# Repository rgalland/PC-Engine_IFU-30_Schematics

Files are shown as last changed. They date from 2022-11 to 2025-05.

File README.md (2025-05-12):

# PC-Engine IFU-30 Reverse engineering
This repository contains:
* kicad files of the main PCB schematics
* kicad files of the RAM mezzanine PCB
* wiki page to explain the circuitry

Potential future development:
* creation of a compatible PCB using SMD component to shrink the board a bit and include RAM on it as well
* add a header for an easy RGB modification

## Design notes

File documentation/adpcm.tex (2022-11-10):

%% LyX 2.3.6 created this file.  For more info, see http://www.lyx.org/.
%% Do not edit unless you really know what you are doing.
\documentclass[english]{article}
\usepackage[T1]{fontenc}
\usepackage[latin9]{inputenc}
\usepackage{babel}
\usepackage{amssymb}
\usepackage{graphicx}
\usepackage[unicode=true]
 {hyperref}
\begin{document}
\title{ADPCM Amplification}
\maketitle

\section{Introduction}

Before being mixed to the audio left and right signals, the ADPCM
signal generated by the M5205 is biased and shrunk, re-amplified and
goes through a few low pass filters.
\begin{figure}
\caption{ADPCM Filter Circuit}

\begin{centering}
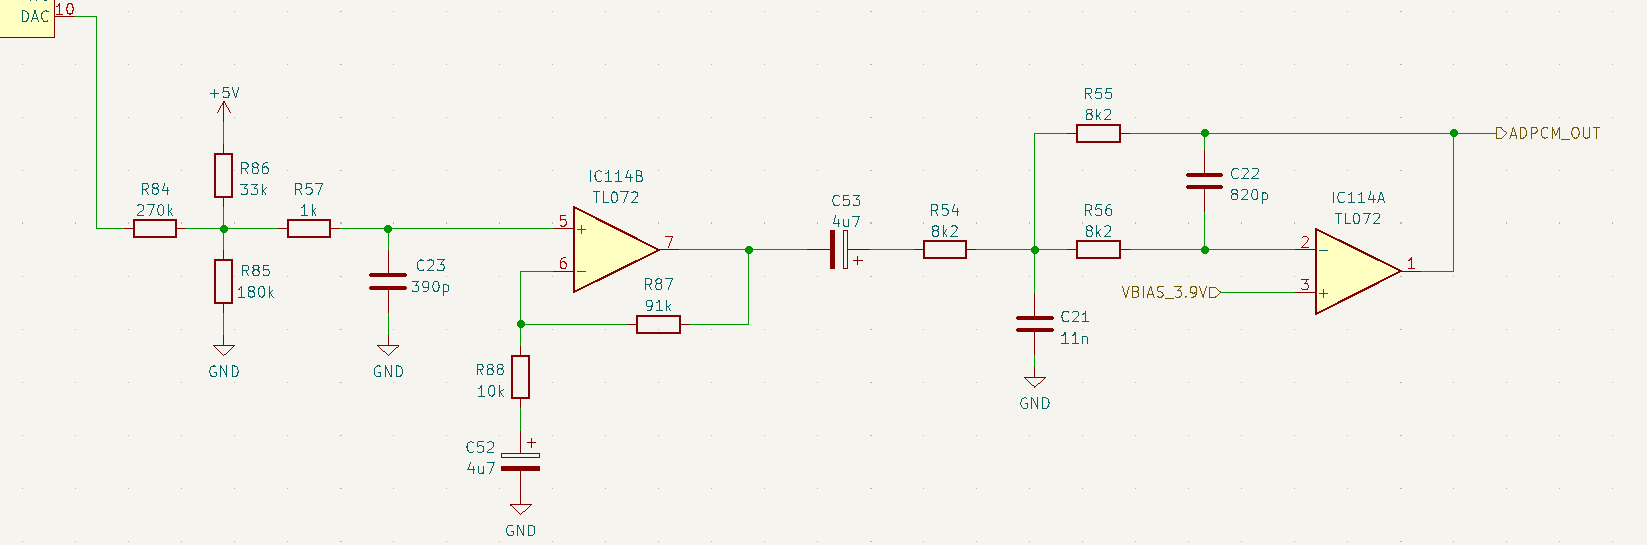
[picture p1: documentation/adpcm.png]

\par\end{centering}
\end{figure}

\section{Biasing}

\begin{figure}
\caption{Biasing and Passive Low-pass Filter}

\begin{centering}
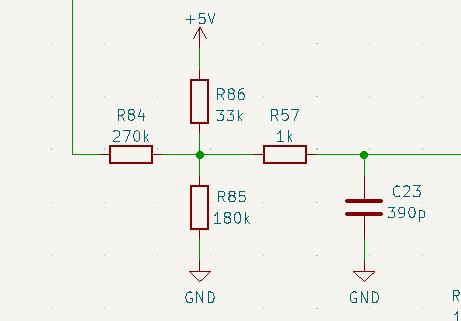
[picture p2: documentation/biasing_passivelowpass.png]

\par\end{centering}
\end{figure}
The biasing is introducted by the R86 and R85 bridge divider connected
to 5V (see Figure 2). We will start with the calculation of the Thevenin
equivalent circuit at R85.

\[
V_{TH_{R85}}=\frac{V_{DAC}/R84+5V/R86+0/R85}{1/R84+1/R86+1/R85}=\frac{V_{DAC}/270k+5/33k}{1/270k+1/33k+1/180k}
\]

\[
V_{TH_{R85}}=\frac{V_{DAC}}{10.682}+3.83V
\]

\[
R_{TH_{R85}}=R84//R86//R85=\frac{1}{1/R84+1/R86+1/R85}=\frac{1}{1/270k+1/33k+1/180k}=25.277k\Omega
\]
As you can see, the DAC output is divided by 10.682 so the signal
is greatly shrunk by the biasing circuit and it is shifted up by 3.83V.

\section{Passive Low-pass filter}

Now that we have determined the Thevenin equivalent, we can calculate
the low pass filter including R57 and C23.

\[
V_{C23}=\frac{Z_{C23}}{R_{TH_{R85}}+R57+Z_{C23}}\times V_{TH_{R85}}=\frac{1/jC23\omega}{R_{TH_{R85}}+R57+1/jC23\omega}\times V_{TH_{R85}}
\]

\[
V_{C23}=\frac{1}{1+j\left(R_{TH_{R85}}+R57\right)C23\omega}\times V_{TH_{R85}}
\]
\linebreak{}
At DC level, when $j\omega=0$, C23 acts an open circuit and therefore
$V_{TH_{R85}}$ is applied directly to V+. $V_{TH_{R85}}$ will include
3.83V and DC bias added in software to VDAC which is typically 2.5V.
Since VDAC is divided by 10.682, a 2.5V DC offset will give 0.234V.
$V_{TH_{R85}}=3.83+0.234\thickapprox4V$\linebreak{}
\linebreak{}
Let's now work out the cut-off frequency of the low-pass filter.

\[
\omega_{C}=\frac{1}{(R_{TH_{R85}}+R57)C23}\rightarrow f_{C}=\frac{1}{2\pi(R_{TH_{R85}}+R57)C23}=\frac{1}{2\pi\times(25.277k+1k)\times390\times10^{-12}}=15538Hz
\]
\linebreak{}
First order filter with -3dB attenuation at $f_{c}=15538Hz$ and -20dB
per decade.

\section{IC114B - Positive Gain Amplifier}

\begin{figure}
\begin{centering}
\caption{Positive Gain Amplifier}
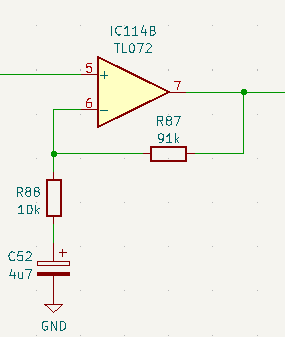
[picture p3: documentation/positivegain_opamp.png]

\par\end{centering}
\end{figure}
IC114B has a negative feedback and the input voltage is connected
to the positive input. Therefore it is configured as an amplifier
with a positive gain. C52 is a fairly large capacitor connected to
ground which ensure gain is only applied at AC level where the opamp
becomes a simple follower at DC level. In other words, the ADPCM signal
is amplified and bias voltage is preserved.\linebreak{}
\linebreak{}
At DC level, when $j\omega=0$, C52 is seen as an open circuit therefore:
\[
V_{IC114B+}=V_{R85}=V_{IC114B-}=V_{IC114BOUT}=4V
\]
AC level, IC114B acts as positive gain amplifer.

\[
V_{IC114B-}=\frac{R88+1/jC52\omega}{R88+1/jC52\omega+R87}\times V_{IC114BOUT}
\]
\linebreak{}
When $j\omega\rightarrow\infty$, capacitors be come short circuits
and we can determine the gain for high frequencies.

\[
V_{IC114B-}=\frac{R88}{R88+R87}\times V_{IC114BOUT}=V_{IC114B+}=V_{R85AC}
\]

\[
Gain=\frac{V_{IC114BOUT}}{V_{R85AC}}=\frac{R88+R87}{R88}=\frac{10k+91k}{10k}=10.1
\]

\[
\frac{V_{IC114BOUT}}{V_{R85AC}}=\frac{R88+1/jC52\omega+R87}{R88+1/jC52\omega}=\frac{1+j(R87+R88)\times C52\omega}{1+jR88C52\omega}
\]
\linebreak{}
To determine the cut frequency of the high-pass filter we know that
gain must be 3dB away from the final final. i.e. $10.1/\sqrt{2}=7.142$

\[
\left|\frac{V_{IC114BOUT}}{V_{R85AC}}\right|=\frac{\left|1+j(R87+R88)\times C52\omega\right|}{\left|1+jR88C52\omega\right|}=\frac{\left|1+j0.4747\omega\right|}{\left|1+j0.047\omega\right|}=\frac{\sqrt{1+0.4747^{2}\omega^{2}}}{\sqrt{1+0.047^{2}\omega^{2}}}
\]

\[
\frac{1+0.4747^{2}\omega_{C}^{2}}{1+0.047^{2}\omega_{C}^{2}}=7.142^{2}=51
\]
\[
1+0.4747^{2}\omega_{C}^{2}=51\times\left(1+0.047^{2}\omega_{C}^{2}\right)
\]

\[
0.4747^{2}\omega_{C}^{2}-51\times0.047^{2}\omega_{C}^{2}=51-1
\]

\[
\omega_{C}^{2}\left(0.4747^{2}-51\times0.047^{2}\right)=50
\]

\[
\omega_{C}=\sqrt{\frac{50}{\left(0.4747^{2}-51\times0.047^{2}\right)}}=21.065
\]
\linebreak{}
It is now possible to work out the cut frequency of the high-pass
filter. 
\[
f_{C}=\frac{\omega_{C}}{2\pi}=\frac{21.065}{2\times3.14}=3.354Hz
\]

\section{IC114A - Multi-Feedback Amplifier}

\begin{figure}

\caption{Multi-Feeback Amplifier}

\begin{centering}
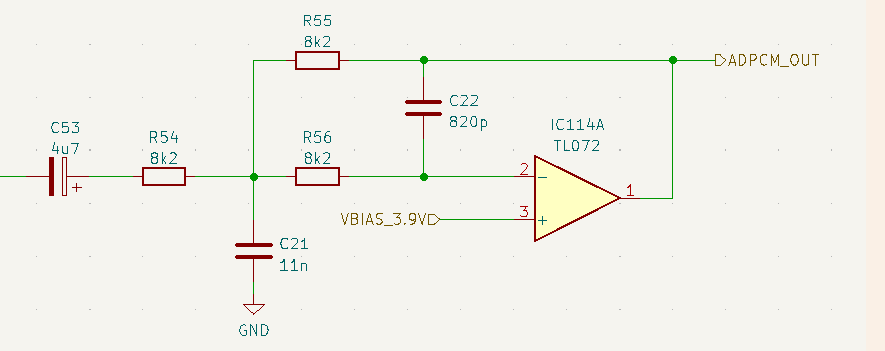
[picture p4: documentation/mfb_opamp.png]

\par\end{centering}
\end{figure}
This opamp is configured as an MFB (multi-feedback) filter which is
a second order low-pass filter but also no gain at DC. For the calculations,
C53 is removed but its purpose is to remove any DC offset before it
is fed to the opamp.\linebreak{}
\linebreak{}
When $j\omega=0$, C53, C21 and C22 act as open circuits. Therefore:

\[
V_{IC114A-}=V_{ADPCMOUT}=V_{IC114B+}=V_{BIAS}=3.90V
\]
When $j\omega\rightarrow\infty$, C22 is a short circuit turning IC114A
into a follower but at this stage C21 is shorting the input signal
to ground so there will be no high-frequency output signal.\linebreak{}
\linebreak{}
To find the transfer function of this opamp circuit, we will break
in down in 2 stages: calculation of voltage at C21 and then calculation
of voltage at IC114A-. To simplify calulations, VBIAS biased will
be switched off to make $V_{IC114A-}=V_{IC114A+}=0V$. With this simplification,
the connection R56 and C22 will be tied to GND. \linebreak{}
\linebreak{}
\[
V_{C21}=\frac{\frac{V_{IC114BOUT}}{R54}+\frac{V_{ADPCMOUT}}{R55}}{\frac{1}{R54}+\frac{1}{R55}+\frac{1}{R56}+jC21\omega}
\]

\[
V_{IC114A-1}=\frac{\frac{V_{ADPCMOUT}}{1/jC22\omega}+\frac{V_{C21}}{R56}}{jC22\omega+\frac{1}{R56}}=0
\]

\[
V_{C21}=-jR56C22\omega\times V_{ADPCMOUT}
\]

\[
\frac{\frac{V_{IC114BOUT}}{R54}+\frac{V_{ADPCMOUT}}{R55}}{\frac{1}{R54}+\frac{1}{R55}+\frac{1}{R56}+jC21\omega}=-jR56C22\omega\times V_{ADPCMOUT}
\]

\[
\frac{V_{IC114BOUT}}{R54}+\frac{V_{ADPCMOUT}}{R55}=-jR56C22\omega\times V_{ADPCMOUT}\times\left(\frac{1}{R54}+\frac{1}{R55}+\frac{1}{R56}+jC21\omega\right)
\]

\[
V_{ADPCMOUT}\times\left(\frac{1}{R55}+jR56C22\omega\times\left(\frac{1}{R54}+\frac{1}{R55}+\frac{1}{R56}+jC21\omega\right)\right)=-\frac{V_{IC114BOUT}}{R54}
\]

\[
\frac{V_{ADPCMOUT}}{V_{IC114BOUT}}=-\frac{1}{R54}\times\frac{1}{\frac{1}{R55}+jR56C22\omega\times\left(\frac{1}{R54}+\frac{1}{R55}+\frac{1}{R56}+jC21\omega\right)}
\]

\[
\frac{V_{ADPCMOUT}}{V_{IC114BOUT}}=-\frac{1}{R54R56}\times\frac{1}{\frac{1}{R55R56}+jC22\omega\times\frac{R55R56+R54R56+R54R55}{R54R55R56}-C21C22\omega^{2}}
\]

\[
\frac{V_{ADPCMOUT}}{V_{IC114BOUT}}=-\frac{1}{R54R56C21C22}\times\frac{1}{\frac{1}{R55R56C21C22}+j\frac{R55R56+R54R56+R54R55}{R54R55R56C21}\omega-\omega^{2}}
\]
\linebreak{}
Since R54=R55=R56, we will replace them with R instead to simplify
the equation:

\[
\frac{V_{ADPCMOUT}}{V_{IC114BOUT}}=-\frac{1}{R^{2}C21C22}\times\frac{1}{\frac{1}{R^{2}C21C22}+j\frac{R^{2}+R^{2}+R^{2}}{R^{3}C21}\omega-\omega^{2}}=-\frac{1}{R^{2}C21C22}\times\frac{1}{\frac{1}{R^{2}C21C22}+j\frac{3}{RC21}\omega-\omega^{2}}
\]

\[
H\left(j\omega\right)=-\frac{1}{1+j3RC22\omega-R^{2}C21C22\omega^{2}}
\]
\linebreak{}
Now that we have the transfer function, we can see that when $j\omega=0$,
the DC gain is 1. \linebreak{}
\linebreak{}
\[
\omega_{C}=\frac{1}{\sqrt{R^{2}C21C22}};\omega_{C}=2\pi f_{C};f_{C}=\frac{1}{2\times\pi\times\sqrt{8.2k\times8.2k\times11\times10^{-9}\times390\times10^{-12}}}=6463Hz
\]
\linebreak{}
The cut-off freuqency is 6463Hz and -40dB percade will be applied
by the filter. The next stage is the Quality factor calculation but
I can't remember how to do that. To get the value, I typed the component
values in \href{http://sim.okawa-denshi.jp/en/OPttool.php}{this link}
and it gave me Q=1.2209.
\end{document}

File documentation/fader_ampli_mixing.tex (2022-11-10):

%% LyX 2.3.6 created this file.  For more info, see http://www.lyx.org/.
%% Do not edit unless you really know what you are doing.
\documentclass[english]{article}
\usepackage[T1]{fontenc}
\usepackage[latin9]{inputenc}
\usepackage{babel}
\usepackage{graphicx}
\usepackage[unicode=true]
 {hyperref}

\makeatletter

%%%%%%%%%%%%%%%%%%%%%%%%%%%%%% LyX specific LaTeX commands.
%% Because html converters don't know tabularnewline
\providecommand{\tabularnewline}{\\}

\makeatother

\begin{document}
\title{Audio Fading, Mixing and Amplification}

\maketitle
\begin{figure}
\caption{Audio Mixing and Amplification}

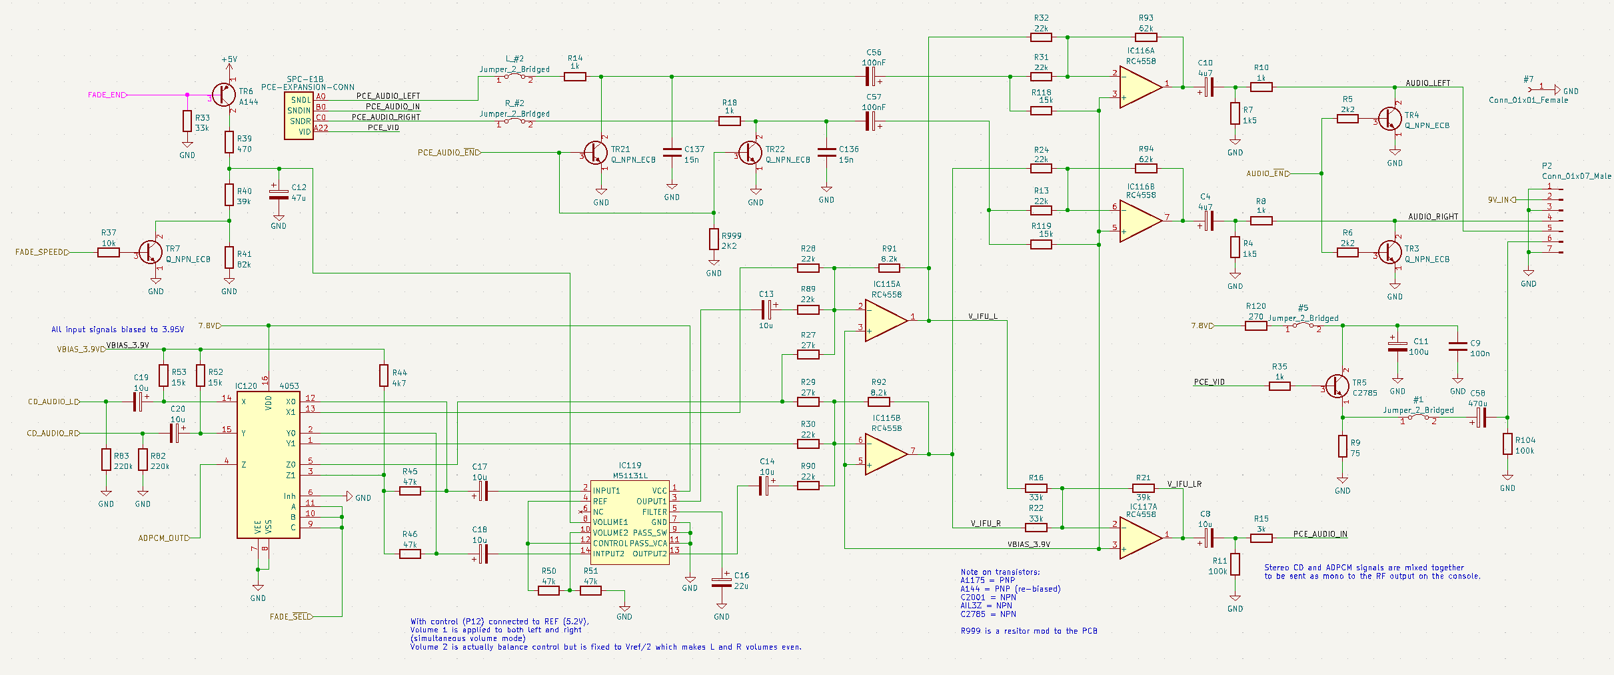
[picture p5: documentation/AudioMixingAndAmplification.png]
\centering{}
\end{figure}

\section{Audio Fading Circuit}

The ADPCM signal and the CD audio left and right channels can be faded
out at 2 different rates via register 180Fh; 2.5s or 6s. In normal
operation i.e. when not fading is applied, TR6 (A144) is constantly
saturated by pulling the base to GND via R33 and this allows C12 to
charge to 5V via R39.\linebreak{}
\linebreak{}
When fading is enabled, the IC output (which I expect to be an open
collector output) to pull up the base to 5V and thus stop sauration.
This will have the effect of discharging C12 through R40 in fast fading
mode and through R40 and R41 in slow fading mode. The fading mode
is controlling TR7: when the IC pulls the base up, it is saturated
which makes it short R41 giving the fast fading mode. When the IC
output is floating, the base no longer receives current and the transistor
is open giving the slow fading mode.

\begin{figure}

\caption{C12 Charging and Discharging}

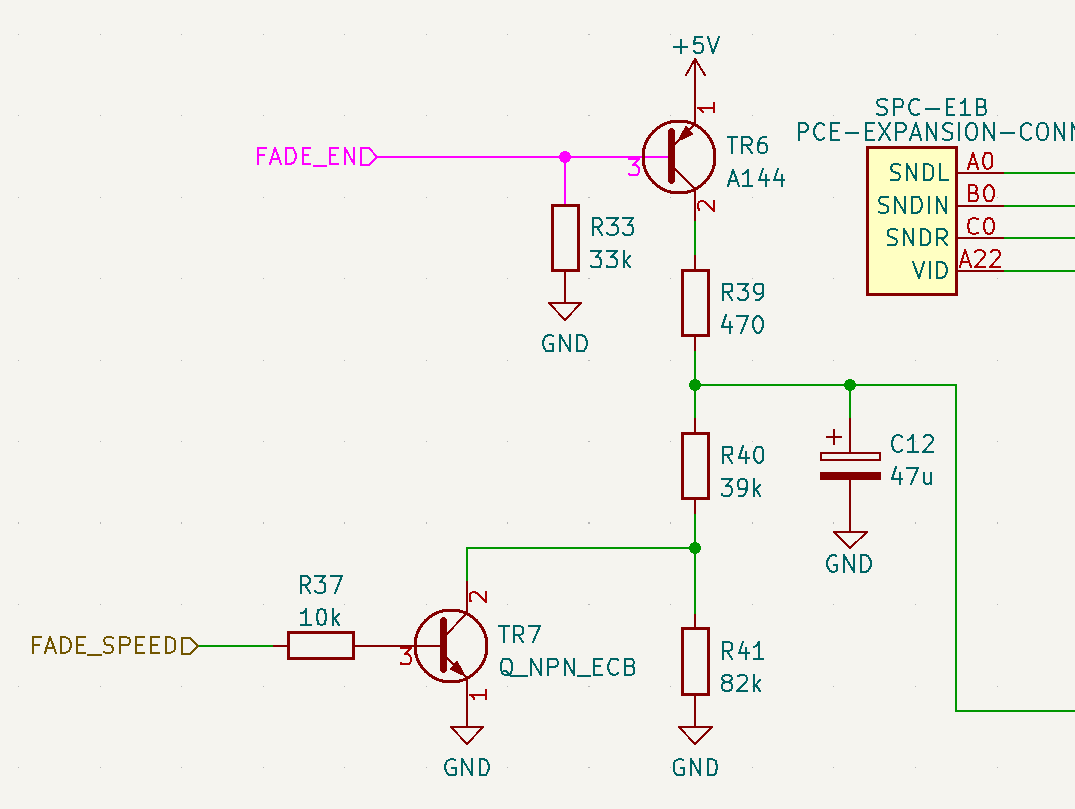
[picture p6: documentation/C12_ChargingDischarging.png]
\centering{}
\end{figure}

\subsection{C12 Charging}

The time constant for the charging of C12 is:

\[
\tau=R39\times C12=470\times47\times10^{-6}=22.09ms
\]
It means that we can consider C12 fully charged after approximately
$3\tau$ or 66ms. Therefore, the sound will recover pretty quickly
as soon as fading is disabled.

\subsection{C12 Discharging}

Discharging will happen at 2 different rates based on the state of
TR7. TR7 close = fast discharge through R40; TR7 opened = slow discharge
through R40 and R41.\linebreak{}
\linebreak{}
The time constant for the fast discharging of C12 is:

\[
\tau_{1}=R40\times C12=39\times10^{3}\times47\times10^{-6}=1833ms
\]
It means that we can consider C12 fully discharged after approximately
$3\tau$ or 5499ms.\linebreak{}
\linebreak{}
The time constant for the slow discharging of C12 is:

\[
\tau_{2}=(R40+R41)\times C12=(39+82)\times10^{3}\times47\times10^{-6}=5687ms
\]
It means that we can consider C12 fully discharged after approximately
$3\tau$ or 17061ms.\linebreak{}
\linebreak{}
We can see that these values are a lot greater than what is mentioned
in the CD-ROM BIOS documentation which mentions 2.5s and 6s. This
is what what we will explain in the section covering the volume chip,
M51131L.\linebreak{}
\begin{figure}
\caption{Fast and Slow Discharge Graphs}

\begin{centering}
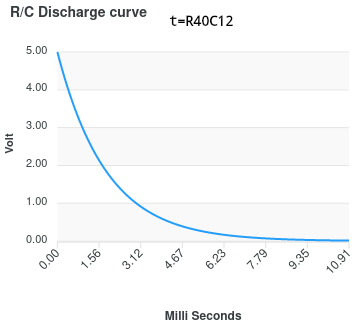
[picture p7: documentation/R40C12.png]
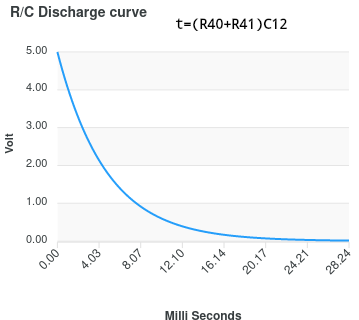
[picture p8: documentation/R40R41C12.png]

\par\end{centering}
\href{https://www.redcrab-software.com/en/Calculator/Electrics/C-Discharge-State}{Graphs generated here!}
\end{figure}

\subsection{BU4053 - Analogue Switch}

\begin{figure}

\caption{Analogue Switch}

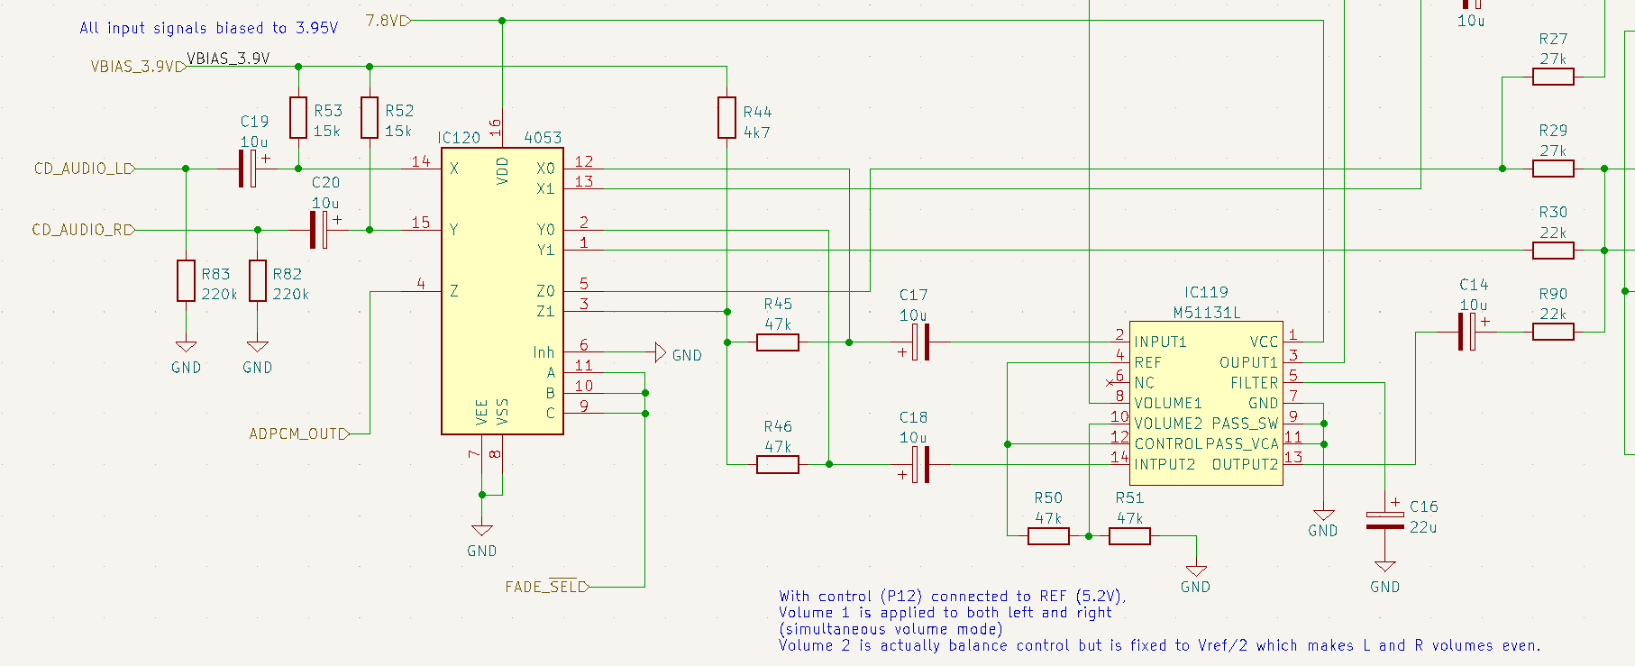
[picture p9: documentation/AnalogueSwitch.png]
\centering{}
\end{figure}
IC4053 is a 3 channel 2:1 analogue switch. Pin X, Y and Z are the
inputs pins for the stereo signals from the CD-ROM and the ADPCM signal.
ADPCM already has 3.9V biasing applied, however the CD-ROM signals
are coupled with C19 and C20 to remove any biasing that may be present
from the CD-ROM but then get biased to 3.9V via R53 and R52. When
FADE\_SELn connected to pin A, B and C is high, the signals are passed
to the rest of the circuitry as is. When FADE\_SELn is low, the signals
are fed to the volume control IC instead, MM51131L. Note that Inh
is tied to GND to always enable it. 

\subsection{Register 180Fh}

This is the register that controls the fading. From looking at the
bios, there is only 1 place where this register is written to with
value 0Fh. From looking at IC connections and using exisitng observations
from Charles MacDonald, the following conclusion can be made: Main
IC P81 is FADE\_SELn and is connected to bit1, Main IC P80 is FADE\_SPEED
and is connected to bit2, Main IC P79 is FADE\_EN and is connected
to bit3. 
\begin{table}
\caption{Register 180Fh}

\centering{}%
\begin{tabular}{|c|c|c|c|}
\hline 
bit3:FADE\_EN & bit2:FADE\_SPEED & bit1:FADE\_SELn & Audio State\tabularnewline
\hline 
\hline 
0 & x & x & No fading\tabularnewline
\hline 
1 & 0 & 0 & 8 second fading\tabularnewline
\hline 
1 & 0 & 1 & No fading (but C12 is discharging slowly)\tabularnewline
\hline 
1 & 1 & 0 & 2.5 second fading\tabularnewline
\hline 
1 & 1 & 1 & No fading (but C12 is discharging fast)\tabularnewline
\hline 
\end{tabular}
\end{table}

\subsection{M51131L - Volume Control IC}

\begin{figure}

\caption{M51131L Attenuation against Volume Control Voltage}

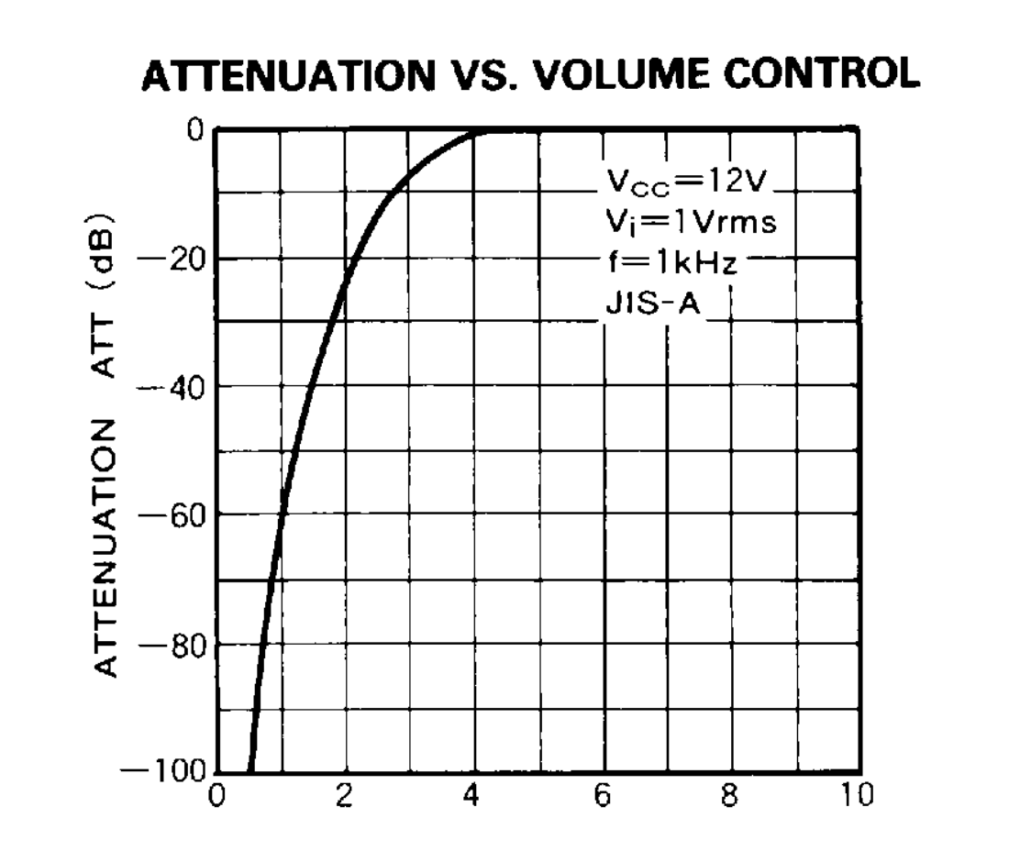
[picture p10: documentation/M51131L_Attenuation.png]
\centering{}
\end{figure}
With control pin (P12) connected to REF (5.2V), Volume 1 is applied
to both left and right channels called simultaneous volume mode in
datasheet and Volume 2 is actually used for balance control. In this
case, Volume 2 is set to Vref/2 which makes L and R volumes equal.
Attenuation is maximum when C12 voltage reaches 0.5V. Based on C12
discharge rates the maximum attenuation will be reached in 4.22s with
$\tau_{1}$ and 13.08s with $\tau_{2}$. The CD-BISO documentation
mentions 2.5 and 6 seconds but Charles McDonald mentions 2.5s and
8s which are more in-line with the calculations. We can see that if
we use the latter values, voltage at C12 reaches 1V with 60dB attenuation
from 4.2V (no attenuation) after 2.5s with $\tau_{1}$ and 8s with
$\tau_{2}$ which implies that the BIOS documentation is inaccurate.

\section{ADPCM and CD Audio Amplification}

\subsection{IC115A\&B - Adders}

The ADPCM signal and the CD audio channels are fed to dual op-amp
IC115 configured as an adder with negative gain. From looking at the
resistor values, we can see that that gain will be less than 1 and
that ADPCM signal will be amplified a bit less than the CD audio channels.
\begin{figure}
\caption{IC115A\&B ADPCM and CD Audio Mixing}

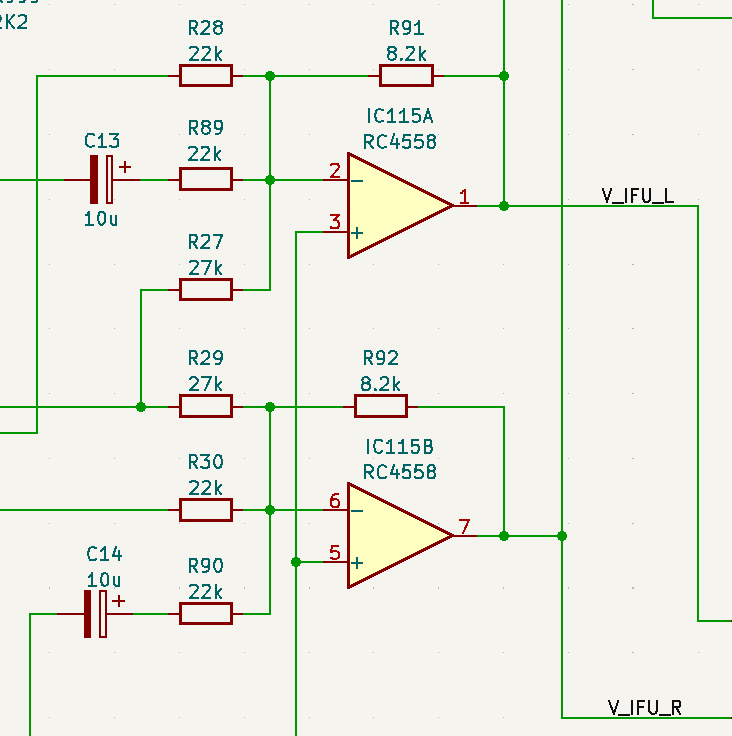
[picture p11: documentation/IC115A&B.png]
\centering{}
\end{figure}
At DC level, we will omit the audio signals and only include the biasing
voltages. 

\[
\frac{V_{BIAS}/(R52+R30)+V_{BIAS}/R29+V_{IFU_{R}}/R92}{1/(R52+R30)+1/R29+1/R92}=V_{BIAS}
\]

\[
\frac{3.9/(15k+22k)+3.9/27k+V_{IFU_{R}}/8.2k}{1/(15k+22k)+1/27k+1/8.2k}=3.9
\]

\[
3.9/37k+3.9/27k+V_{IFU_{R}}/8.2k=3.9/5.376k
\]

\[
V_{IFU_{R}}=3.9\times(1/5.376k-1/37k-1/27k)\times8.2k
\]

\[
V_{IFU_{R}}=3.9V
\]

\[
V_{IFU_{L}}=3.9V
\]
This confirms that biasing will be present on the output.\linebreak{}
\linebreak{}
At AC level, we will ignore the biasing voltages to concentrate on
the audio signals.

\[
\frac{V_{CD_{R}}/R30+V_{ADPCM}/R29+V_{FADE_{R}}/R90+V_{IFU_{R}}/R92}{1/R30+1/R29+1/R90+1/R92}=0
\]

\[
V_{CD_{R}}/22k+V_{ADPCM}/27k+V_{FADE_{R}}/22k+V_{IFU_{R}}/8.2k=0
\]

\[
V_{IFU_{R}}=-8.2k\times(V_{CD_{R}}/22k+V_{ADPCM}/27k+V_{FADE_{R}}/22k)
\]
\[
V_{IFU_{R}}=-\left(V_{CD_{R}}\times8.2/22+V_{ADPCM}\times8.2/27+V_{FADE_{R}}\times8.2/22\right)
\]
\[
V_{IFU_{L}}=-\left(V_{CD_{L}}\times8.2/22+V_{ADPCM}\times8.2/27+V_{FADE_{L}}\times8.2/22\right)
\]
When not in fading mode, gain is 8.2/22 = 0.373 for CD audio channels
and 8.2/27 = 0.304 for ADPCM signal. When fading is enabled, CD audio
channels are conencted directly to the M51131L inputs howver ADPCM
goes through a 47k resitor. I would expext this is due to the 150kohm
resistance on the M51131L inputs and therefore adding the 47k resistor
in series maintains the 22/27 ratio applied in normal mode between
CD and ADPCM as 150/(47+150) is close to 22/27. 

\subsection{IC117A - Adder}

\begin{figure}

\caption{IC117A Configured as Adder}

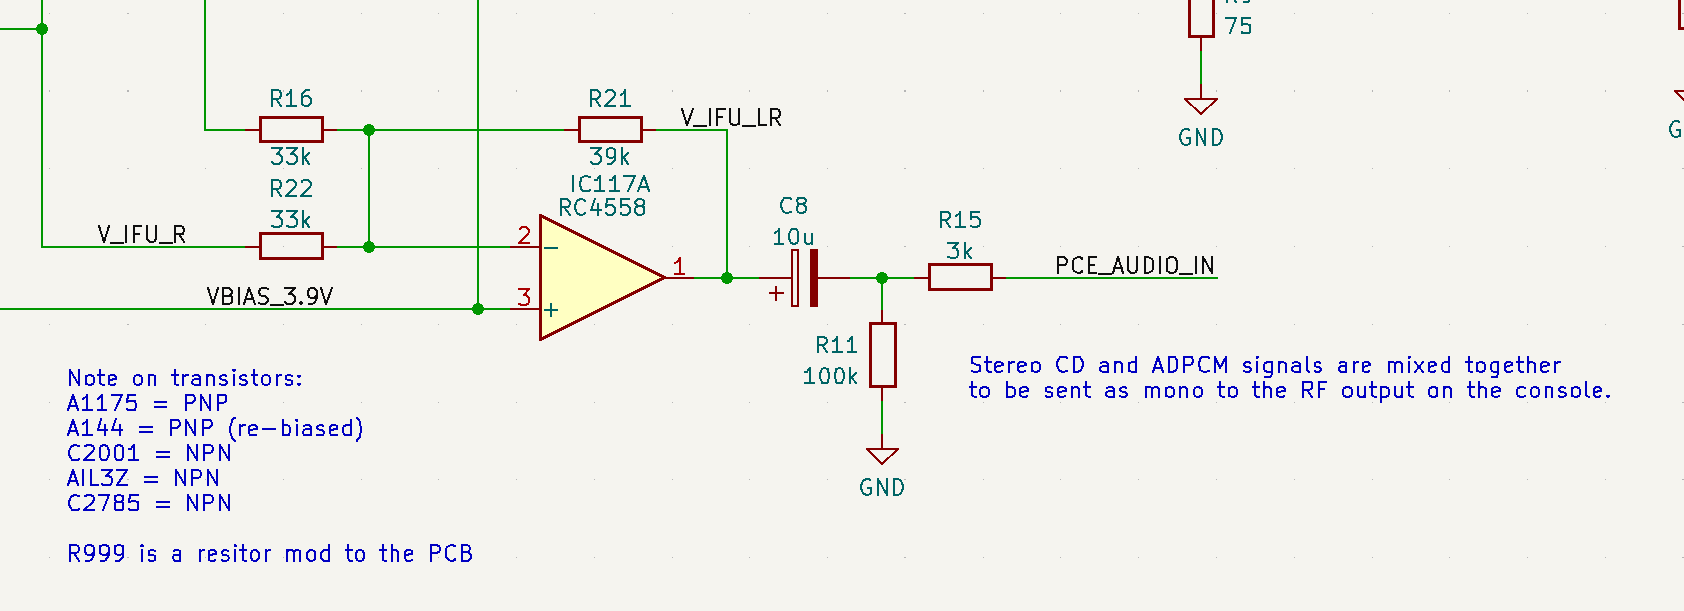
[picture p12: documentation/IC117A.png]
\centering{}
\end{figure}
This opamp mixes the IFU signals (CD and ADPCM) to send then back
as mono to the PC-Engine to be present on the RF connector (which
is always mono).\linebreak{}
\linebreak{}
At DC level, we will omit the audio signals and only include the biasing
voltages.

\[
\frac{V_{IFUL}/R16+V_{IFUR}/R22+V_{IFULR}/R21}{1/R16+1/R22+1/R21}=V_{BIAS}
\]
\[
\frac{3.9/33k+3.9/33k+V_{IFULR}/39k}{1/33k+1/33k+1/39k}=3.9
\]
\[
V_{IFULR}=39k\times3.9\times(1/11.595k-1/33K-1/33K)
\]
\[
V_{IFULR}=3.9V
\]
At AC level, we will ignore the biasing voltages to concentrate on
the audio signals.

\[
\frac{V_{IFUL}/R16+V_{IFUR}/R22+V_{IFULR}/R21}{1/R16+1/R22+1/R21}=0
\]
\[
V_{IFUL}/33k+V_{IFUR}/33k+V_{IFULR}/39k=0
\]
\[
V_{IFULR}=-V_{IFUR}\times39/33-V_{IFUR}\times39/33
\]
Gain is 39/33 = 1.18 and signal is inverted which effectively cancels
out the inversion from the previous stage.

\subsection{PCE Audio Signals}

\begin{figure}

\caption{PCE Audio Signals}

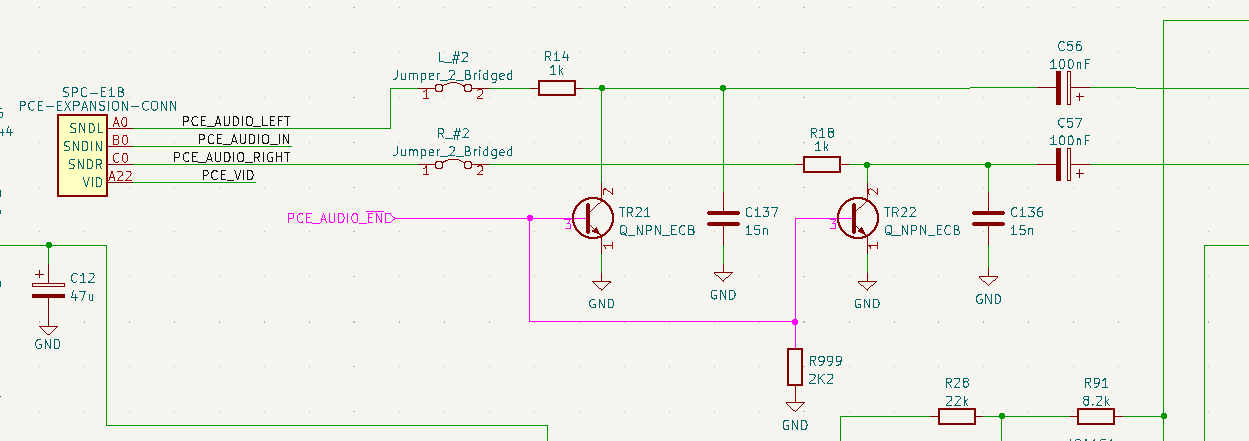
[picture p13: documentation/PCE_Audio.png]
\centering{}
\end{figure}
PC-Engine console left and right audio signals are fed to the IFU
PCB in order to be mixed witht the CD and ADPCM signals. When the
console is not inserted or not powered, TR21 and TR22 are saturated
takin gthese signals to ground probably to stop picking up noise.
C56 and C57 are coupling capacitors removing any DC. Each channel
has a passive low-pass filter with $f_{C}=1/2\pi RC=1/\left(2\pi\times1k\times15\times10^{-9}\right)=10612Hz$.

\subsection{IC116A\&B - Adders}

\begin{figure}

\caption{IC116A\&B Adders}

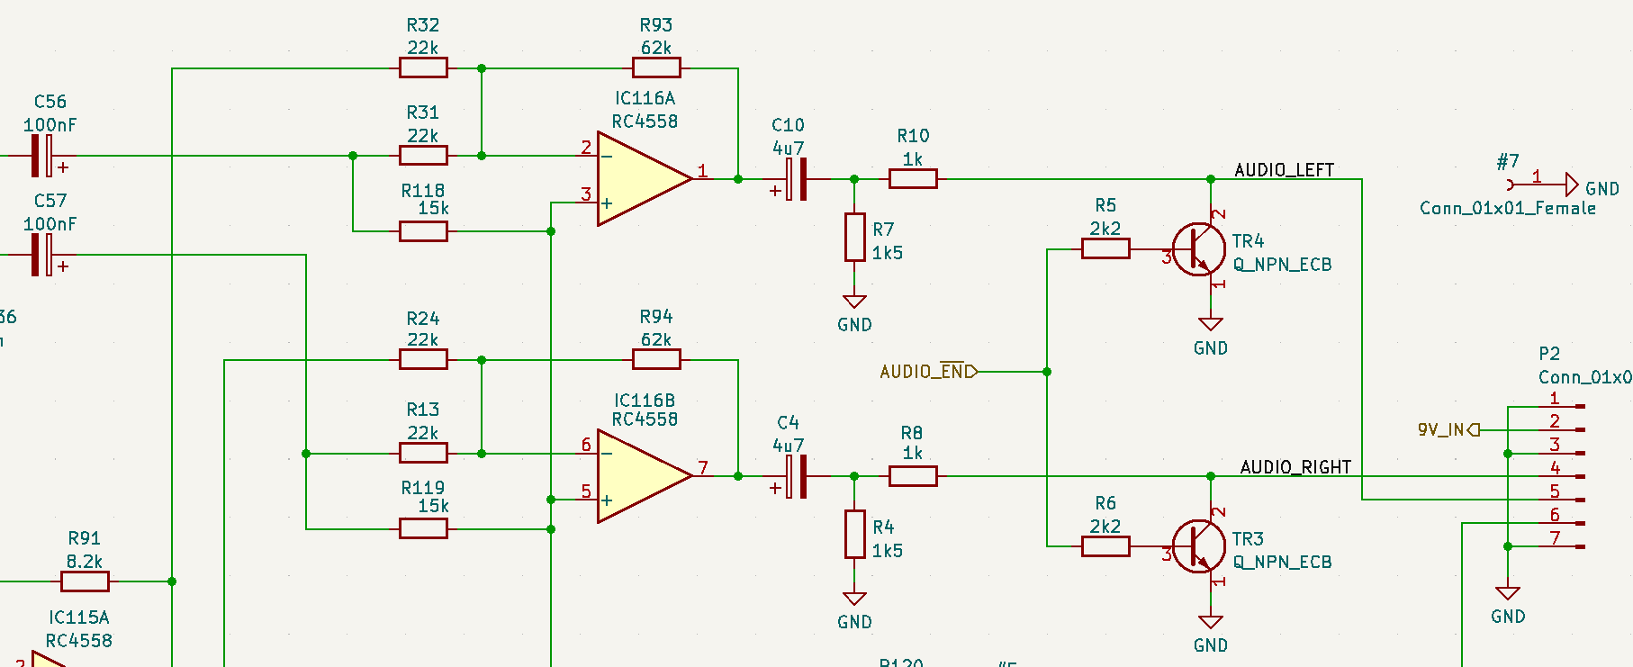
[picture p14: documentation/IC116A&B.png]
\centering{}
\end{figure}
The purpose of these opamps are to mix the PCE audio signals with
the IFU audio signals. IC116A\&B are configured as an adder with negative
gain. From looking at the resistor values, we can see that that gain
will be greater than 1 in such way that it will restitute the CD audio
amplitude. ADCPM amplitude will be slightly less becaiuse of the previous
stage. \linebreak{}
\linebreak{}
At DC level, we will omit the audio signals and only include the biasing
voltages.

\[
\frac{V_{IFUL}/R32+V_{BIAS}/(R118+R31)+V_{AUDIOL}/R93}{1/R32+1/(R118+R31)+1/R93}=V_{BIAS}
\]
\[
3.9/22k+3.9/(15k+22k)+V_{AUDIOL}/62k=3.9\times(1/22k+1/(15k+22k)+1/62)
\]
\[
V_{AUDIOL}=62k\times3.9\times(1/11.285k-1/22K-1/37K)
\]
\[
V_{IFULR}=3.9V
\]
At AC level, we will ignore the biasing voltages to concentrate on
the audio signals.

\[
\frac{V_{IFUL}/R32+V_{PCEL}/R31+V_{AUDIOL}/R93}{1/R32+1/R31+1/R93}=0
\]
 
\[
V_{IFUL}/R32+V_{PCEL}/R31+V_{AUDIOL}/R93=0
\]
 
\[
V_{AUDIOL}=-R93\times(V_{IFUL}/R32+V_{PCEL}/R31)
\]
 
\[
V_{AUDIOL}=-V_{IFUL}\times62/22-V_{PCEL}\times62/22
\]
 Gain is 62/22 = 2.818. Multiplied by previous gain, we get $8.2/22\times62/22=1.05$
close enough to 1 (by 5\%). Before the signals leave the board, TR4
and TR3 can kill the signals when AUDIO\_ENn is high. This can come
from various sources like 5V not present, PC-Engine not plugged in
or main IC disabling audio. No documentation explain how the latter
could be achieved. 
\end{document}

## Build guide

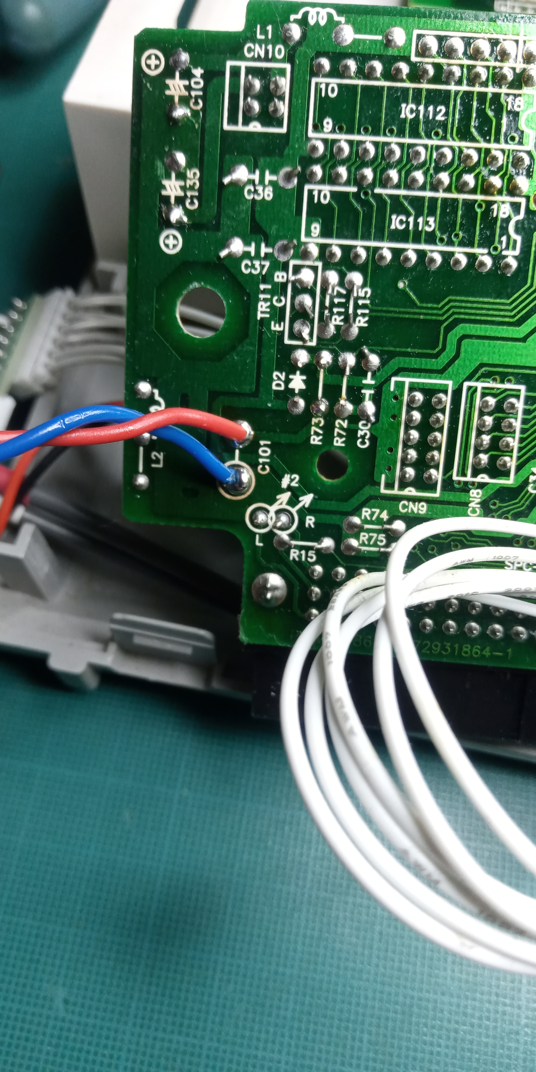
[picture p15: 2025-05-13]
modifications/SRAM_CAP_Mod_Step5.jpg

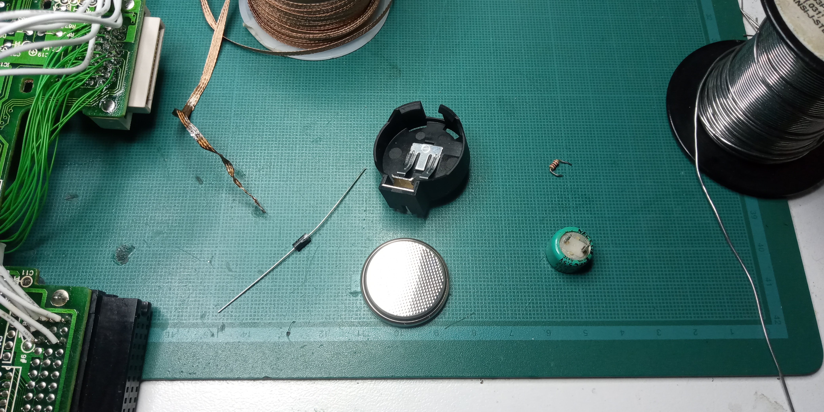
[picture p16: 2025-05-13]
modifications/SRAM_CAP_Mod_Step2.jpg

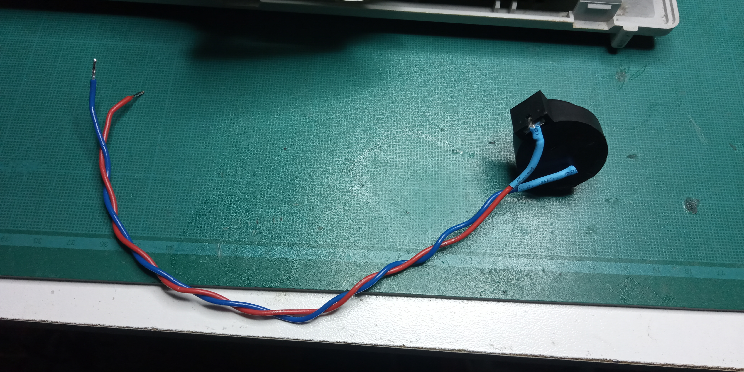
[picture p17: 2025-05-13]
modifications/SRAM_CAP_Mod_Step3.jpg

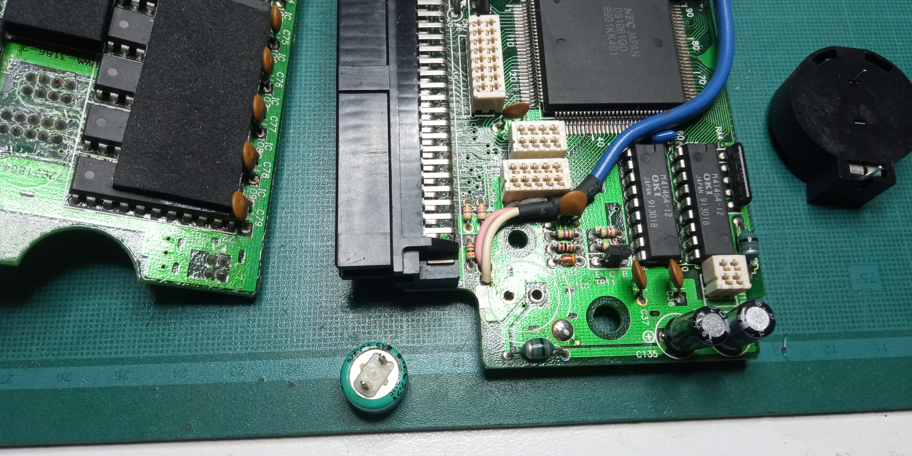
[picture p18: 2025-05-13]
modifications/SRAM_CAP_Mod_Step1.jpg

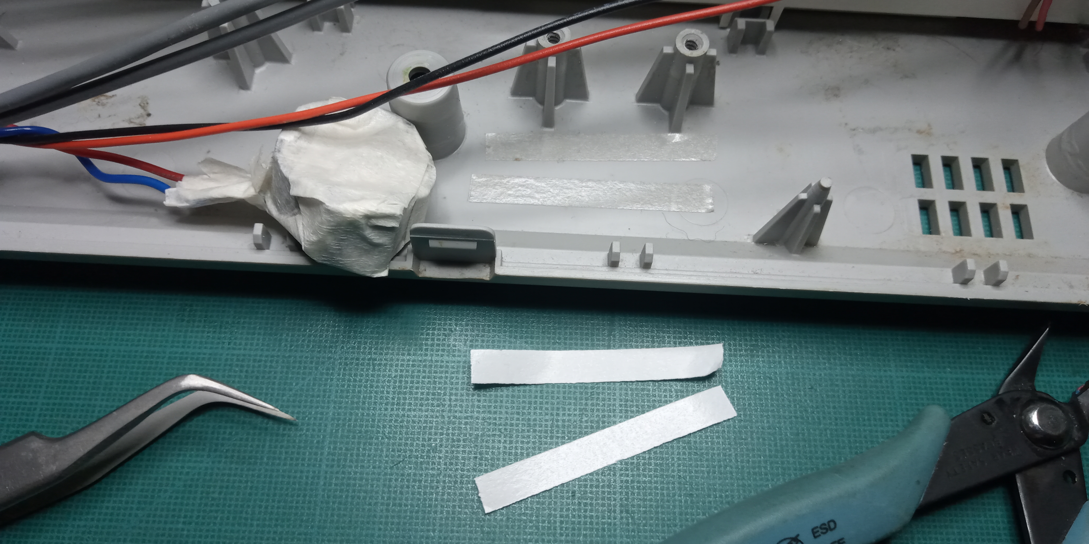
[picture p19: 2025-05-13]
modifications/SRAM_CAP_Mod_Step6.jpg

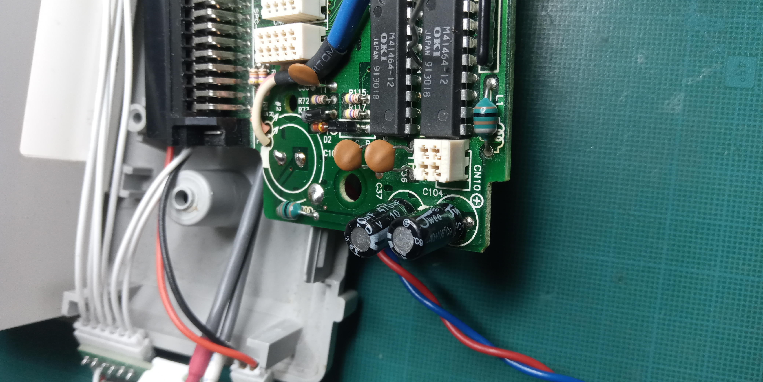
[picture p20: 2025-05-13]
modifications/SRAM_CAP_Mod_Step4.jpg

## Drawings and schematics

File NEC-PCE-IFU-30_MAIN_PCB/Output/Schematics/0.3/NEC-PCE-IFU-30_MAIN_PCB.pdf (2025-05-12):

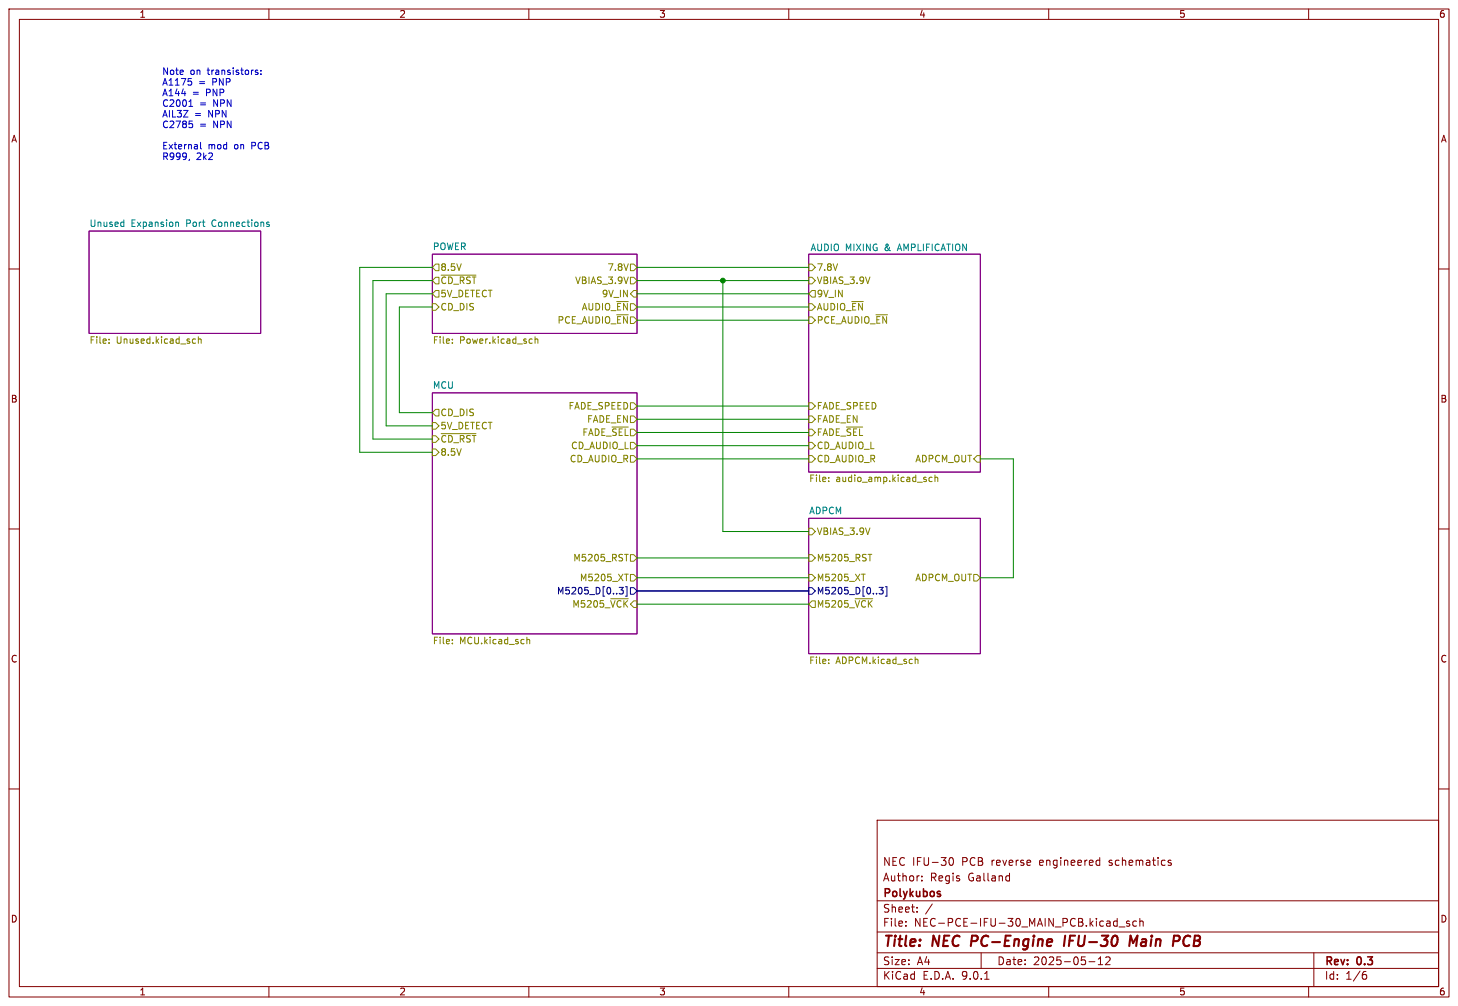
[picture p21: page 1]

Note on transistors: A1175 = PNP

External mod on PCB R999, 2k2

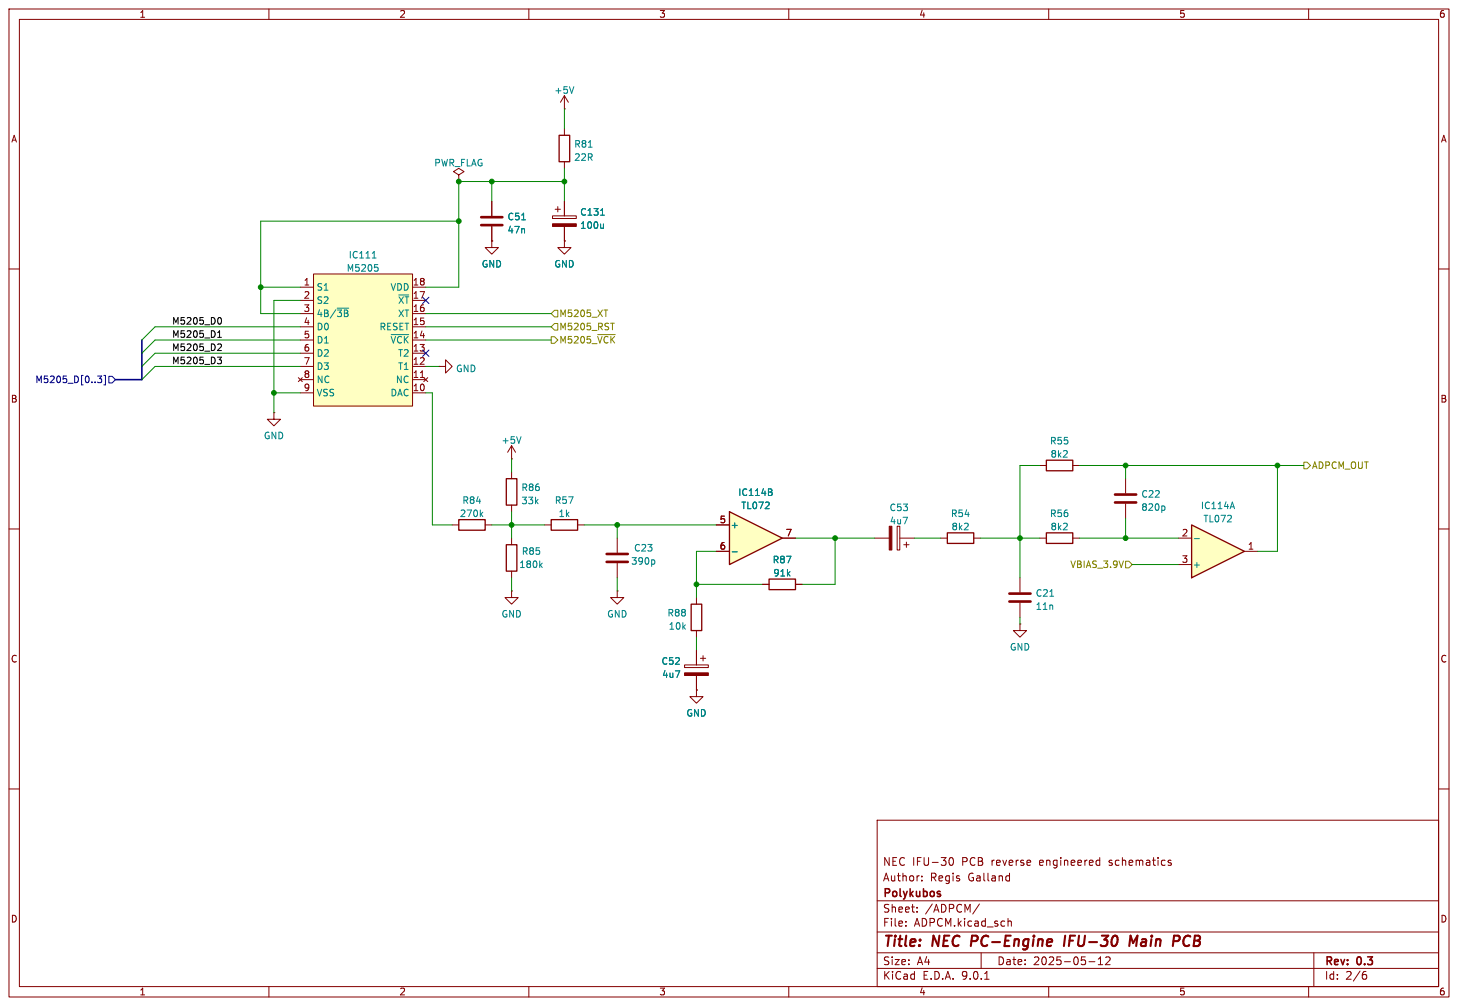
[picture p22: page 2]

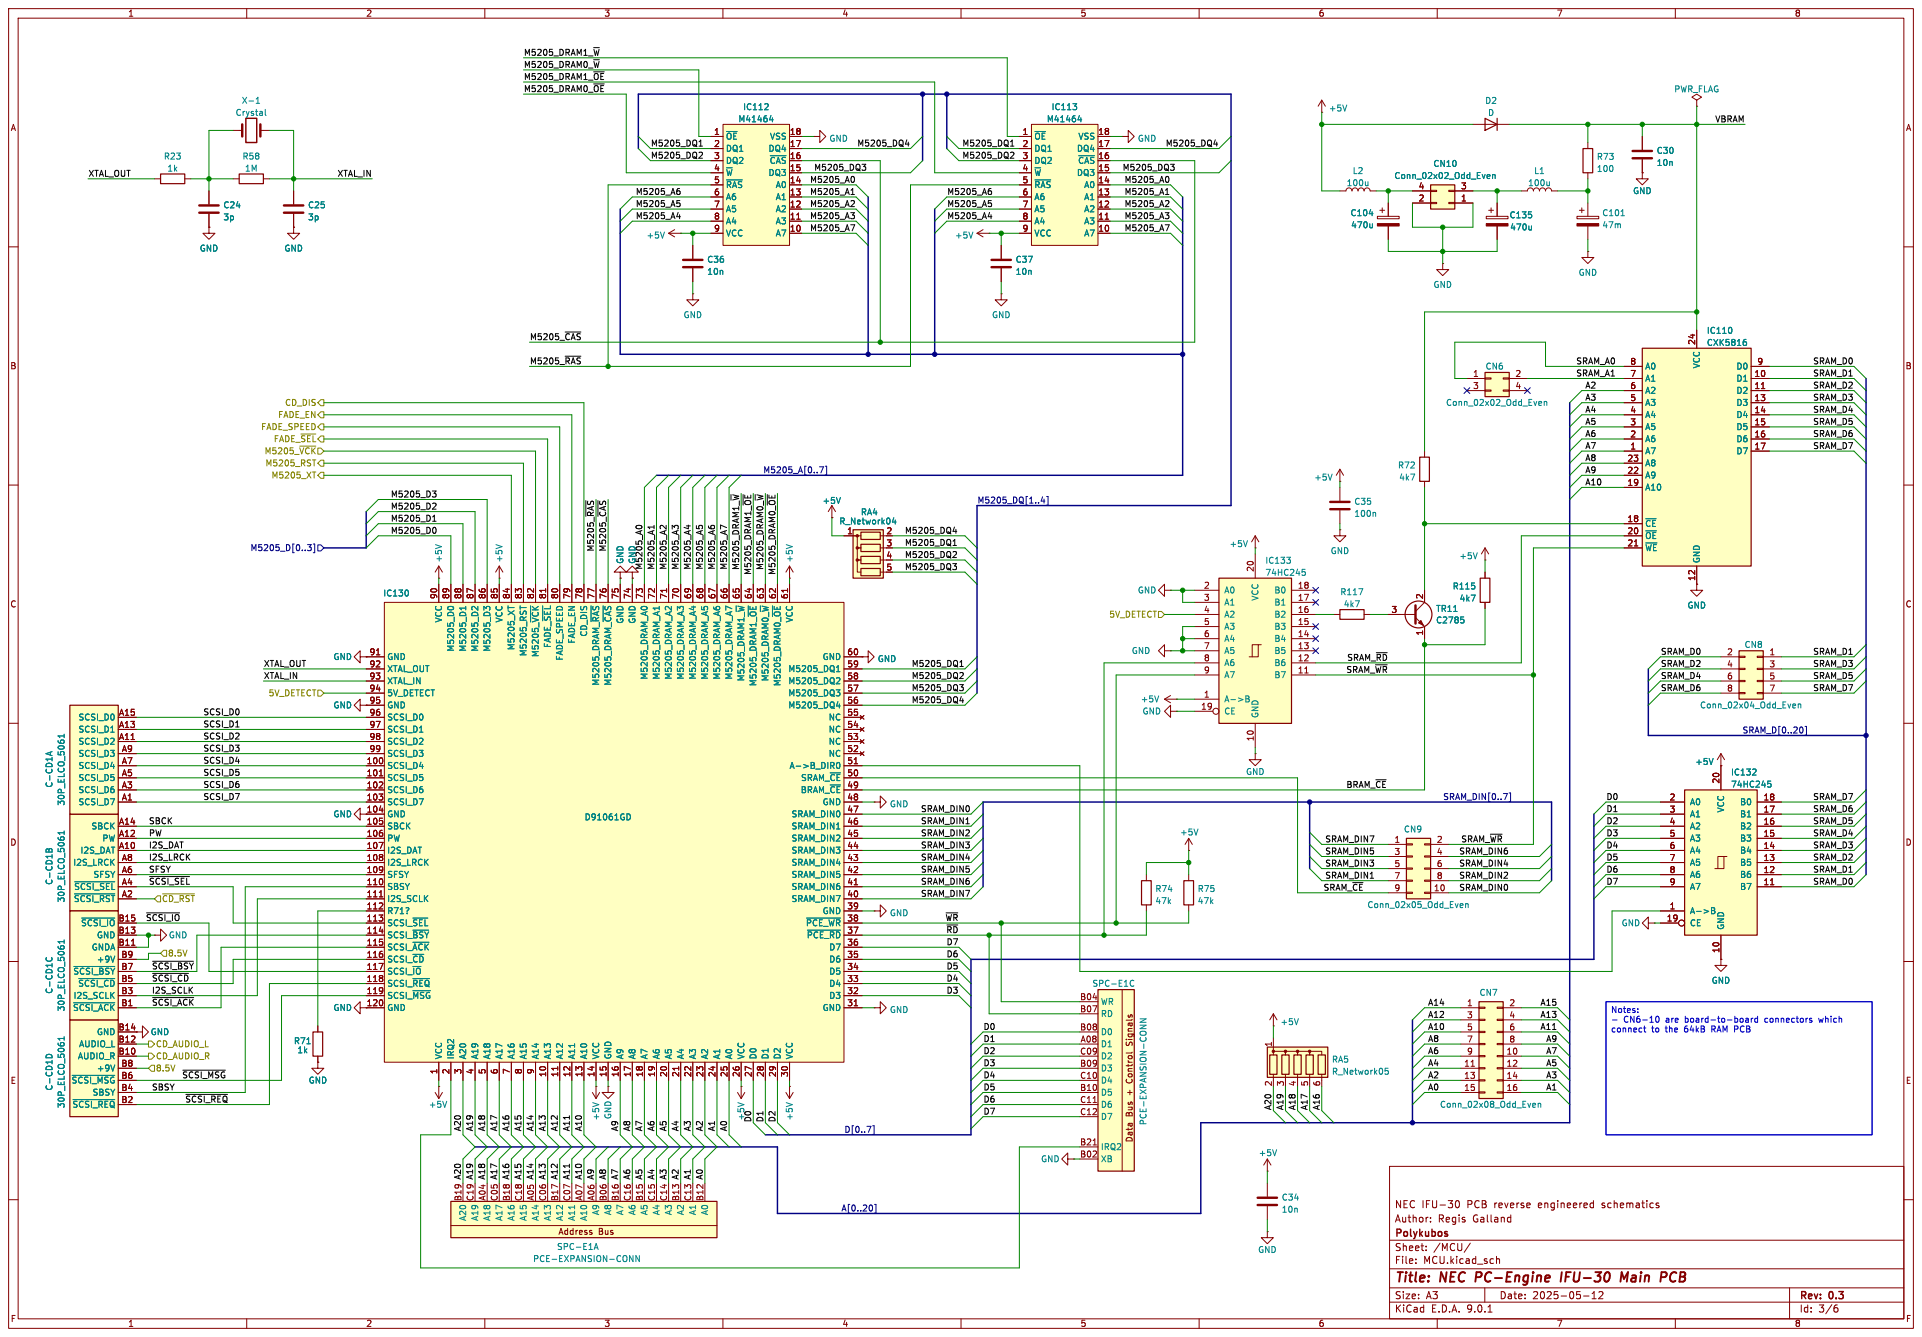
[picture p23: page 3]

IRQ2 B21 XB B02SPC-E1C PCE-EXPANSION-CONN

6 RA5 R_Network05 GND GND Data Bus + Control Signals WR B04 RD B07 D0 B08 D1 A08 D2 C09 D3 B09 D4 C10 D5 B10 D6 C11 D7 C12

connect to the 64kB RAM PCB

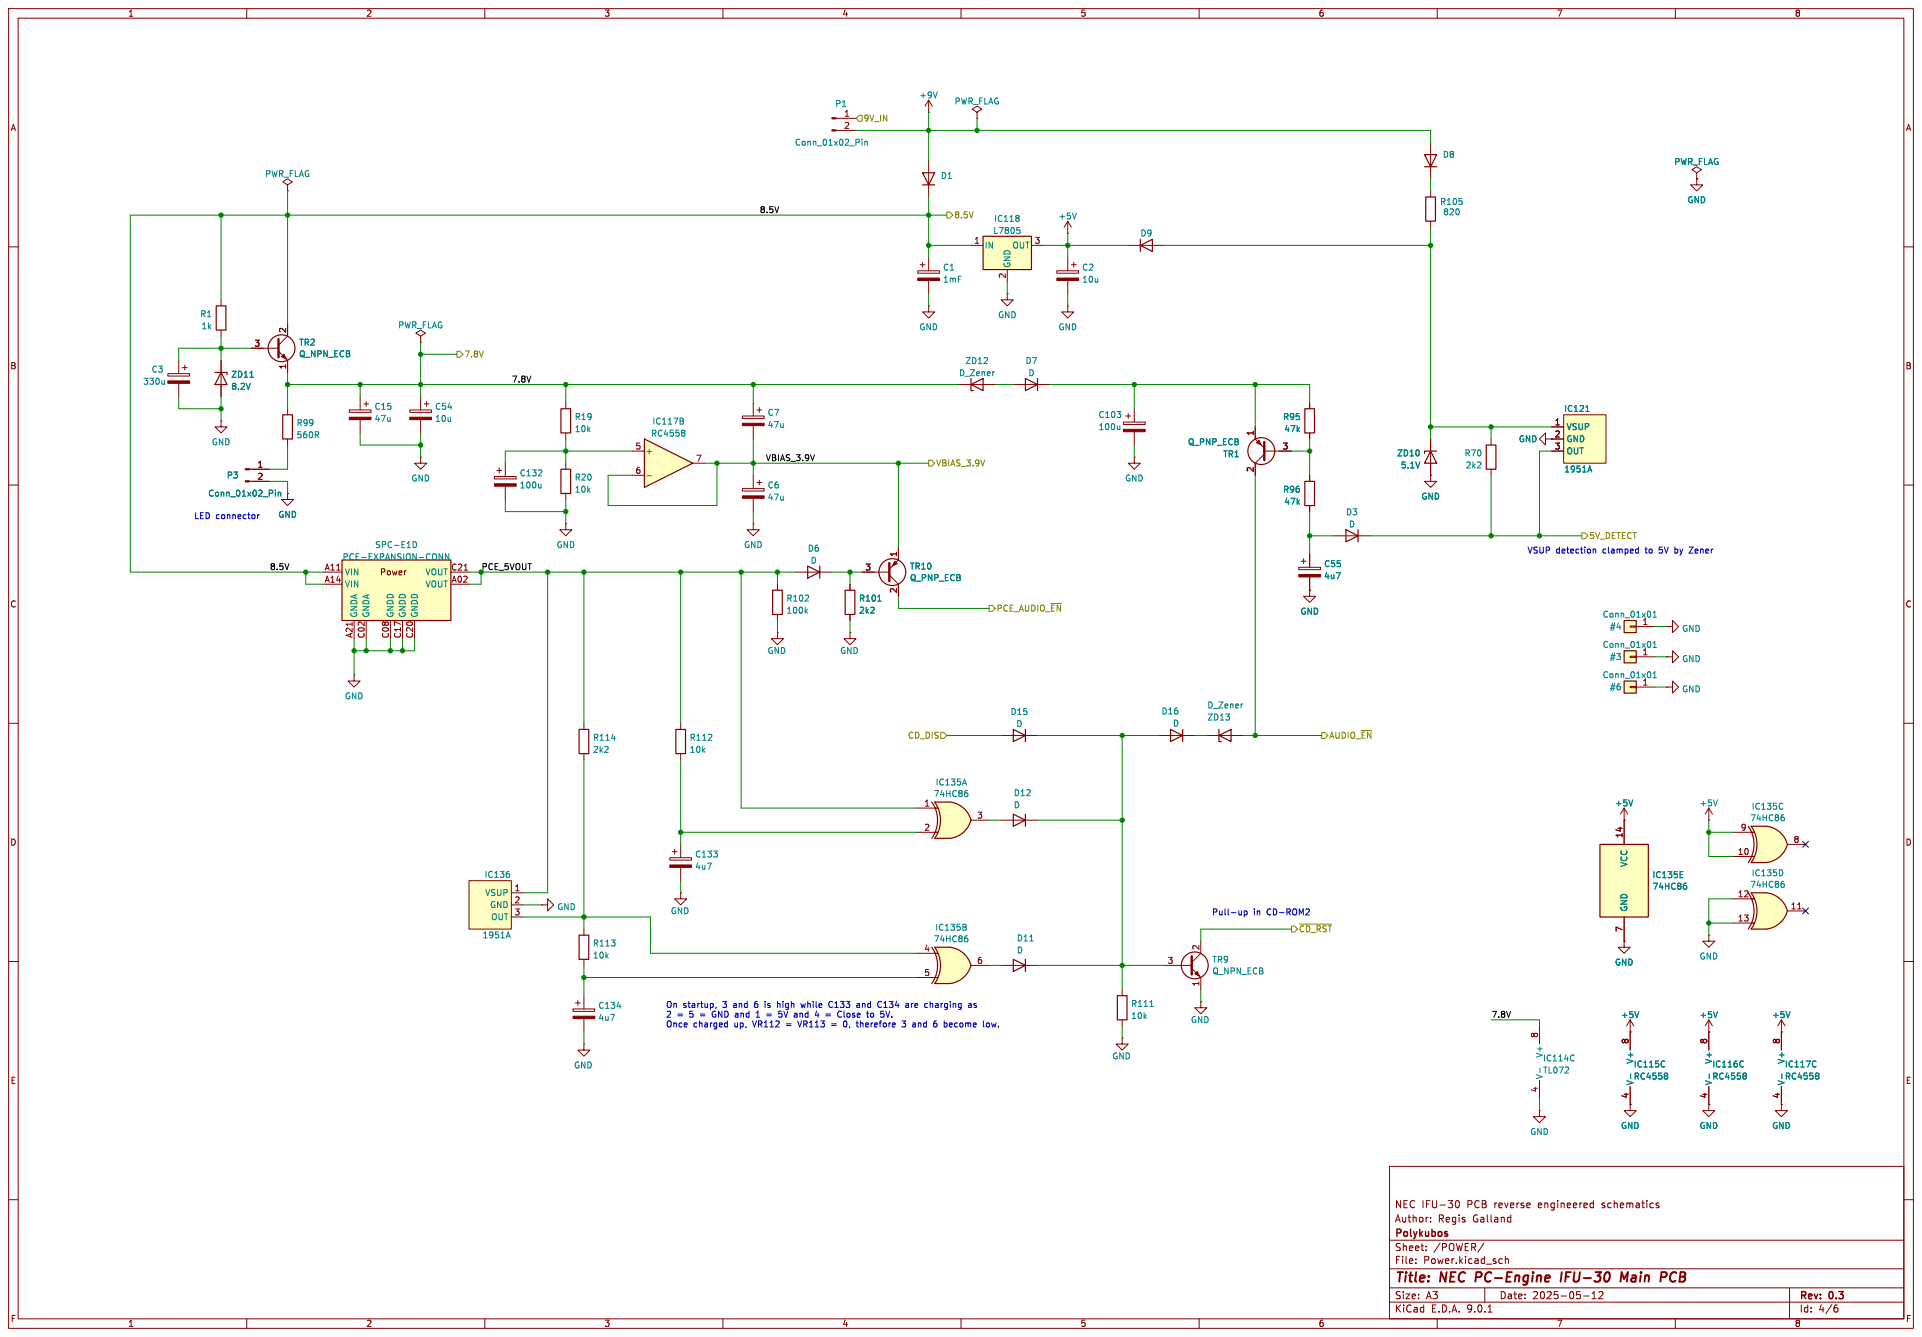
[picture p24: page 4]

PCE-EXPANSION-CONN GND

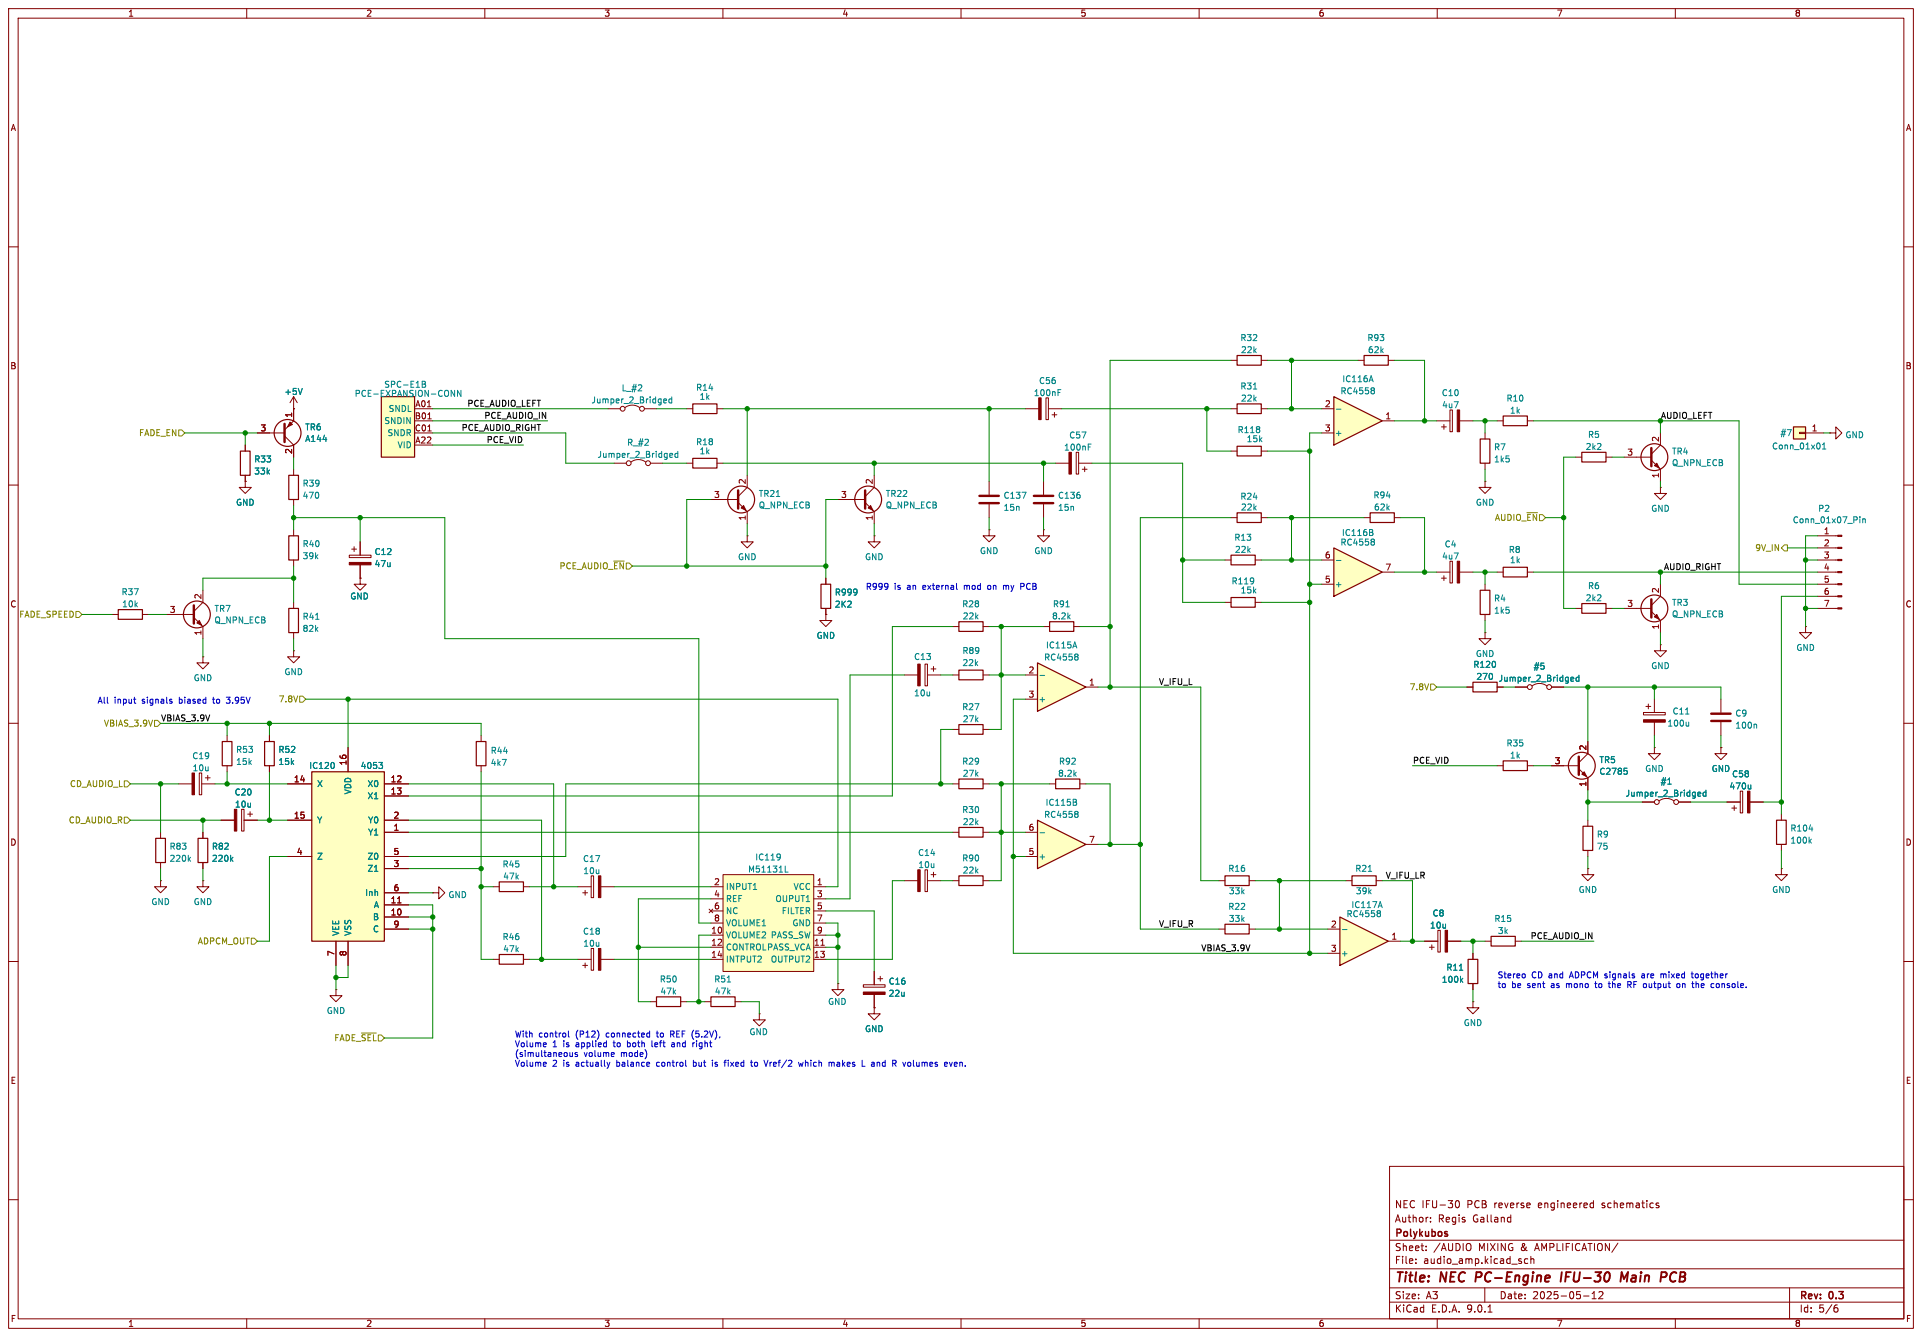
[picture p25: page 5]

62k SNDL A01 SNDIN B01 SNDR C01 VID A22 SPC-E1B

All input signals biased to 3.95V

Stereo CD and ADPCM signals are mixed together

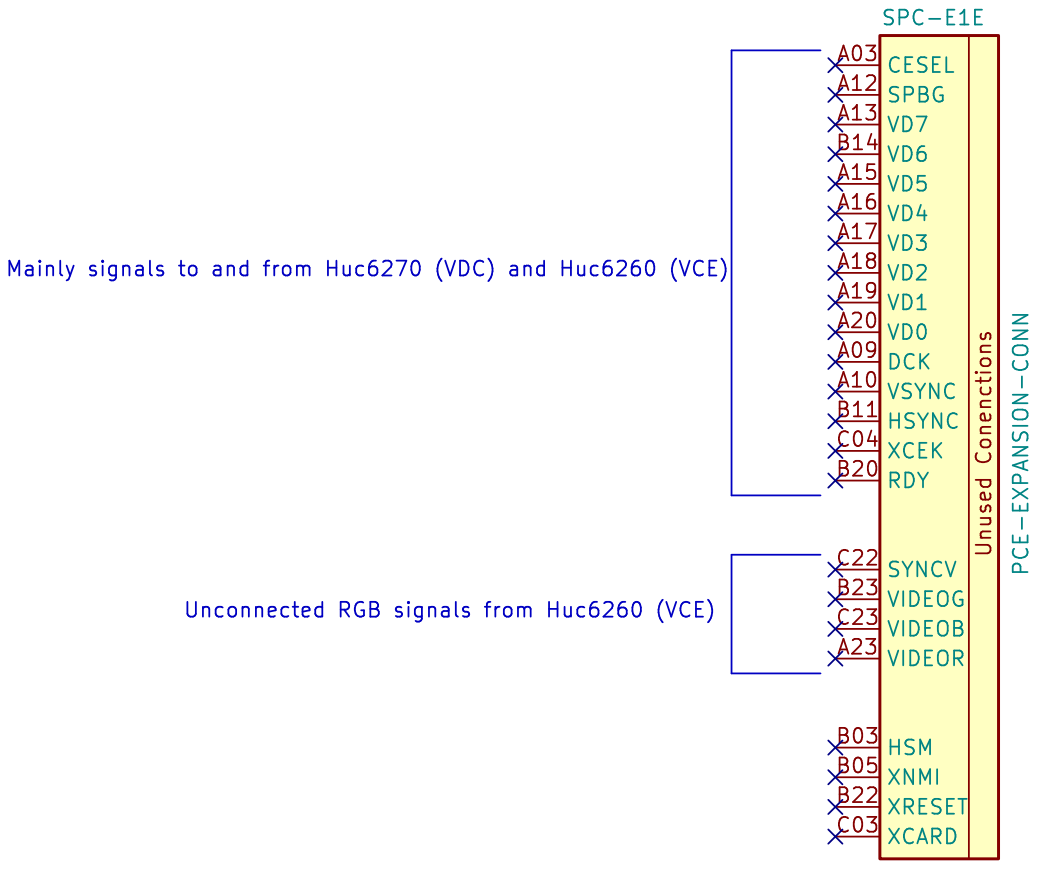
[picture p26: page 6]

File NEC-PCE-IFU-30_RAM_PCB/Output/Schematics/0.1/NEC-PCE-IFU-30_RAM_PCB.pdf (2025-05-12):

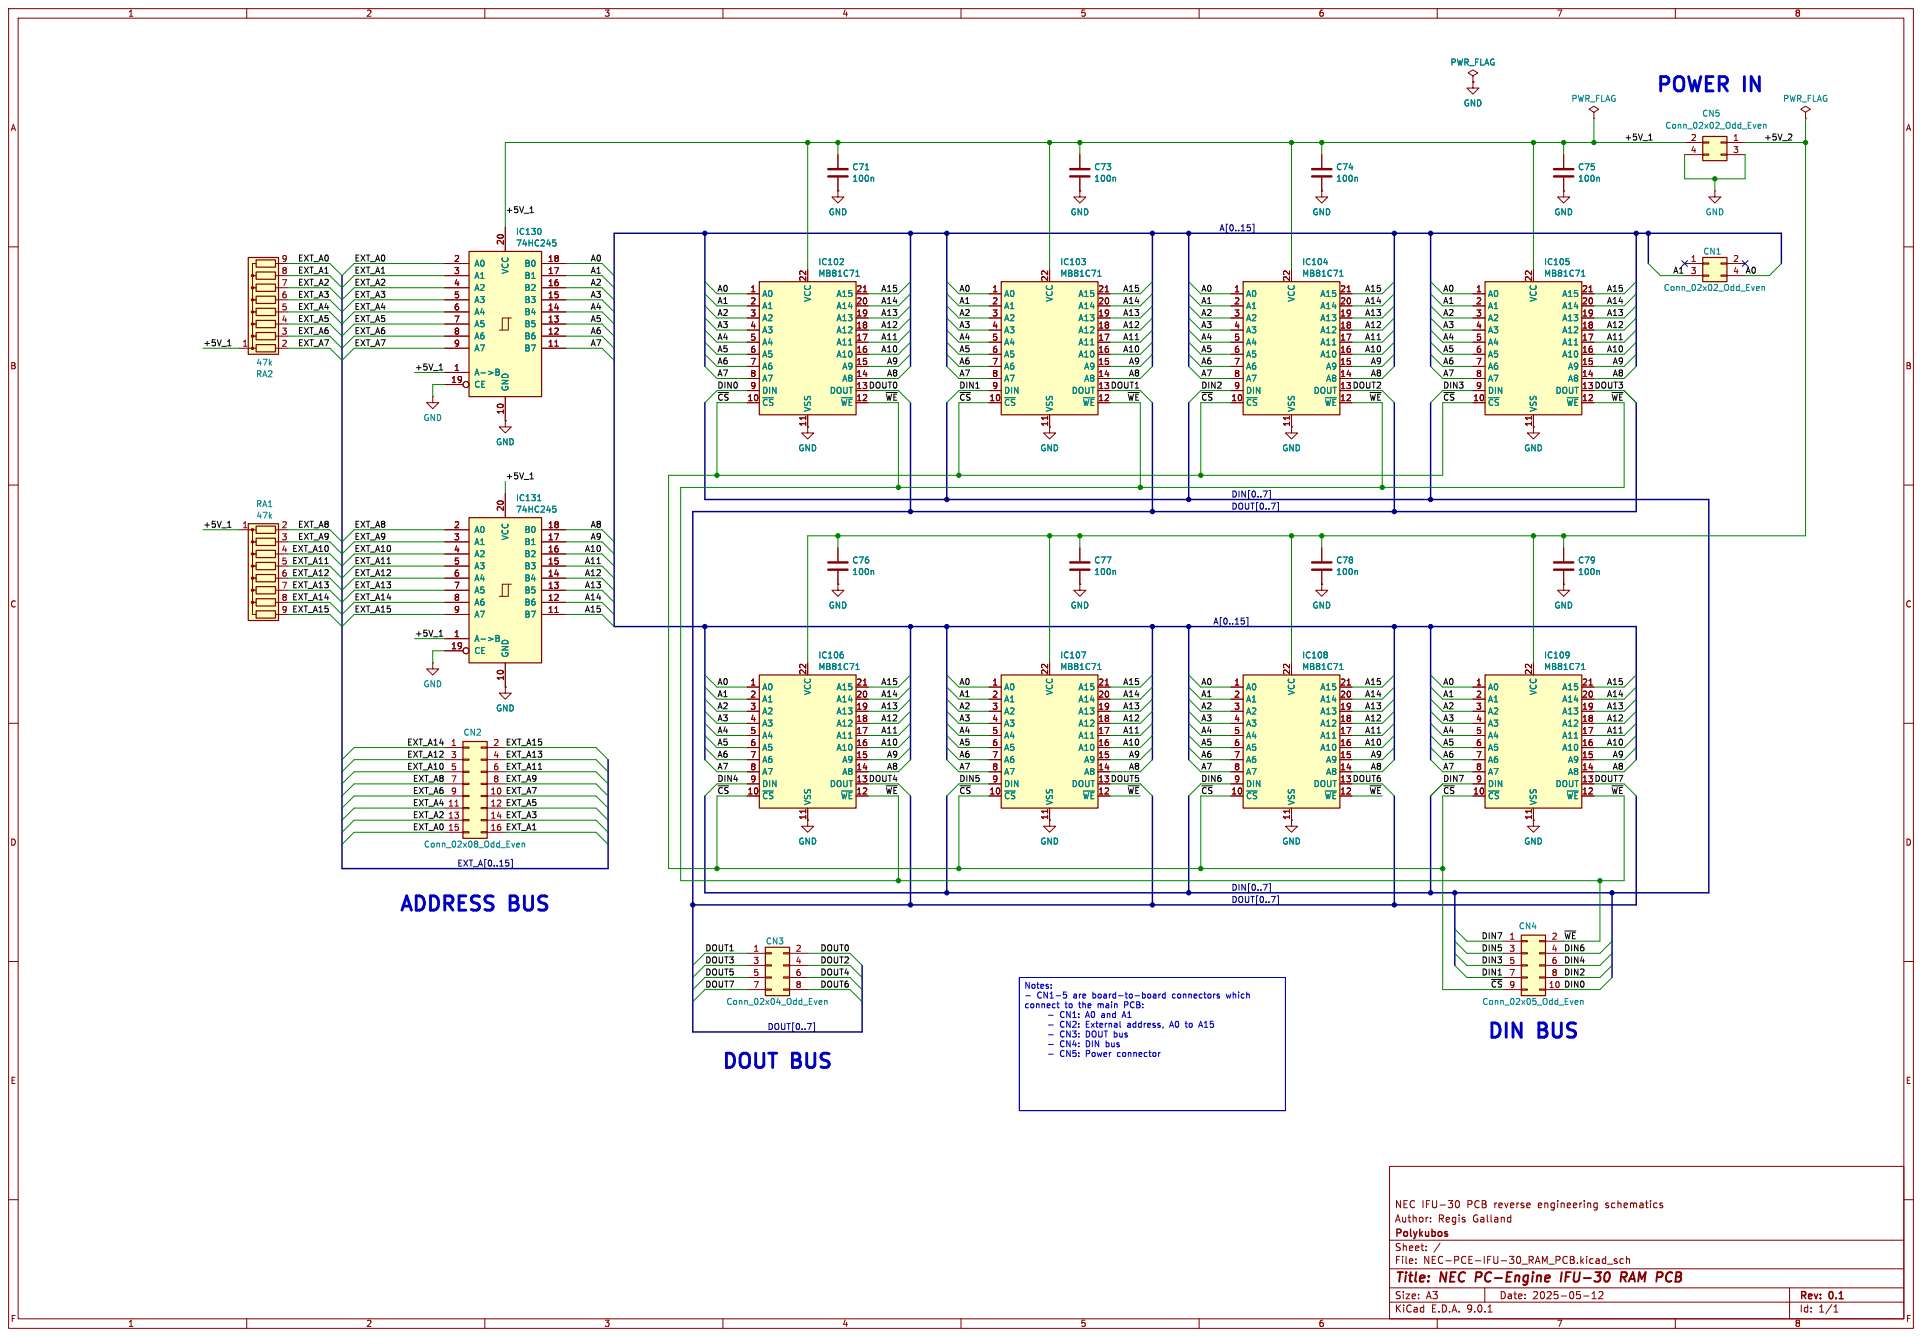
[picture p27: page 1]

- CN5: Power connector ADDRESS BUS

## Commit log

2022-10-24 First commit.
    [ADPCM.kicad_sch, MCU.kicad_sch, NEC-PCE-IFU-30.kicad_sch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]
2022-10-24 PCE expansion port added with only relevant pins.
    [ADPCM.kicad_sch, MCU.kicad_sch, NEC-PCE-IFU-30.kicad_sch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]
2022-10-26 Fixed mistake in ADPCM page and added notes about opamps.
    [ADPCM.kicad_sch, MCU.kicad_sch, NEC-PCE-IFU-30.kicad_sch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]
2022-10-26 All calculations added.
    [ADPCM.kicad_sch, NEC-PCE-IFU-30.kicad_sch, Power.kicad_sch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]
2022-10-30 Documentation started.
    [ADPCM.kicad_sch, MCU.kicad_sch, NEC-PCE-IFU-30.kicad_sch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]
2022-11-10 Documentation update
    [ADPCM.kicad_sch, MCU.kicad_sch, NEC-PCE-IFU-30.kicad_sch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]
2023-03-14 Unsused pins from expansion conenctor on 1 page. CD conenctor signals added.
    [ADPCM.kicad_sch, MCU.kicad_sch, NEC-PCE-IFU-30.kicad_sch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]
2024-04-09 Fixed a few typos and mainly renamed connections to CD-ROM with more accurate descriptions
    [ADPCM.kicad_sch, MCU.kicad_sch, NEC-PCE-IFU-30.kicad_sch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]
2025-05-12 RAM PCB added and project split for each PCB
    [ADPCM.kicad_sch, MCU.kicad_sch, NEC-PCE-IFU-30.kicad_sch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]
2025-05-12 Files added
    [ADPCM.kicad_sch, MCU.kicad_sch, NEC-PCE-IFU-30_MAIN_PCB.kicad_pro.kicad_sch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]
2025-05-12 Some tidying up with names and libraries. Main PCB output directory with schematics
    [NEC-PCE-IFU-30_MAIN_PCB.kicad_sch]
2025-05-13 Rev 0.3 is ready. Mistake was found in the BRAM voltage section and it now makes a lot more sense.
